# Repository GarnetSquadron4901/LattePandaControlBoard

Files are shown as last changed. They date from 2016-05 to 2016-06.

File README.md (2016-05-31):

# LattePanda FRC Driver Station
This is Garnet Squadron's next iteration to the control board. This one dumps the typical laptop and opts for a LattePanda Windows 10 single-board computer with Arduino Leonardo Co-Processor. This repo will hold Windows software, Arduino firmware, design files, and documentation.

## Features
- 16 20mA LED Outputs
- 16 General Purpose I/O
- 16 Analog Inputs
- 16 PWM Outputs
- Backup battery for safe shutdowns
- Auto power-on with AC connect
- LattePanda 
	- Windows 10 Professional
	- 4GB RAM
	- 64GB SSD
	- Intel Cherry Trail Z8300 Quad Core 1.8GHz
	- 3 USB Ports (2 USB 2.0, 1 USB 3.0)
	- Ethernet 10/100
	- 7" Capacitive Touch Screen (1024 x 600)
	- WiFi
	- Bluetooth

## How it works
The Arduino Leondaro connects with I/O expansion chips:

- Microchip MCP23017 - 16-Bit GPIO Expander with I2C Interface
- NXP PCA9685 - 16 channel PWM Driver
- TI CD74HC4067 Analog Multiplexer
- TI TLC59282 16-Channel Constant-Current LED Driver

There is a 2000 mAh LiPo battery that can provide backup power for an estimated 1 hour. While the battery life isn't great, the intended purpose is to provide power long enough to shutdown Windows 10 between matches. Override inputs will be available to:

- Keep the board powered on until battery life reaches ~5%
- Power button to turn on the system even when off of AC power.

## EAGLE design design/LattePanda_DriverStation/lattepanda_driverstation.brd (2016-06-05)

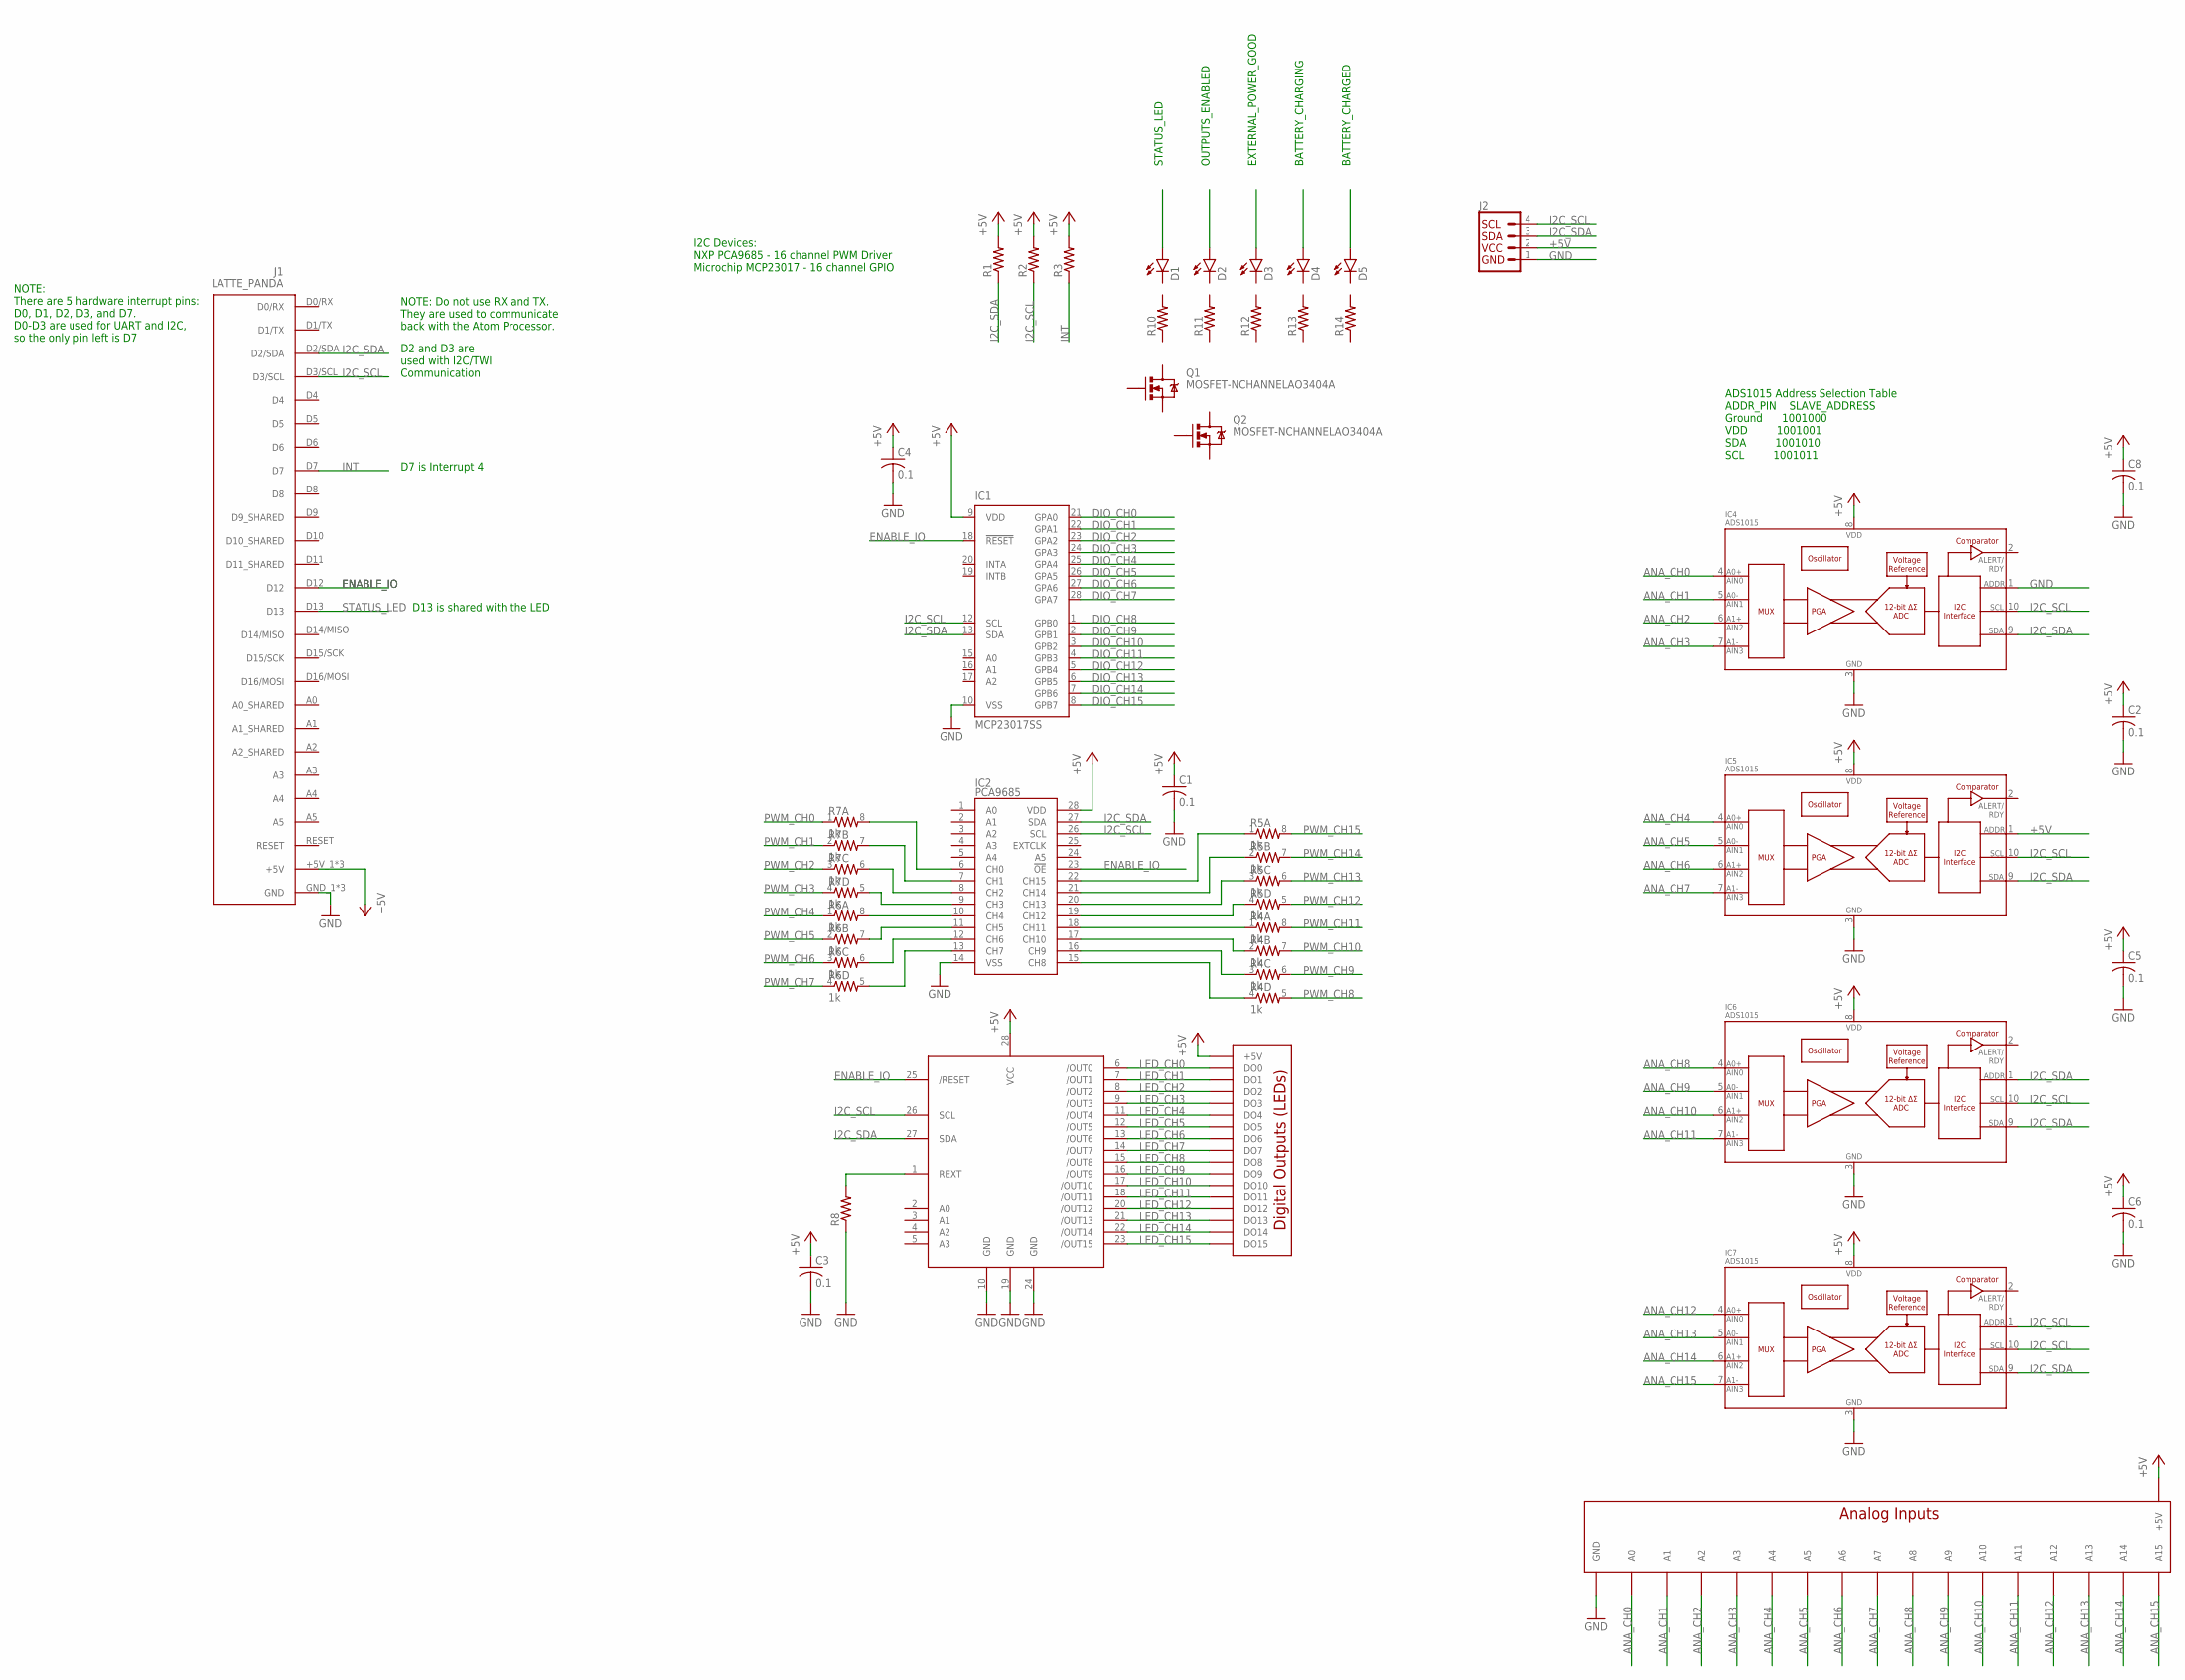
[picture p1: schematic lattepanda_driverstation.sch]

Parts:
C1, C2, C3, C4, C5, C6, C8: 0.1; C1206
D1, D2, D3, D4, D5: LED1206; LED-1206
IC1: MCP23017SS; SSOP28
IC2: PCA9685; TSSOP-28_4MM
IC3: TLC59116; TSSOP28
IC4, IC5, IC6, IC7: ADS1015; MSOP10
J1: LATTE_PANDA
J2: I2C_STANDARD; 1X04
Q1, Q2: MOSFET-NCHANNELAO3404A; SOT23-3
R1, R2, R3, R10, R11, R12, R13, R14: R-US_M1206; M1206
R4, R5, R6, R7: 1k; 0603-ARV
R8: R-US_R1206; R1206
U$1: ANALOGHEADER
U$2: DIGITALOUTPUTS; DIGITALOUT

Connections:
+5V: C1.1, C2.1, C3.1, C4.1, C5.1, C6.1, C8.1, IC1.9 (VDD), IC2.28 (VDD), IC3.28 (VCC), IC4.8 (VDD), IC5.1 (ADDR), IC5.8 (VDD), IC6.8 (VDD), IC7.8 (VDD), J1.+5V_1 (+5V), J1.+5V_2 (+5V), J1.+5V_3 (+5V), J2.2, R1.2, R2.2, R3.2, U$1.+5V@0 (+5V), U$1.+5V@1 (+5V), U$1.+5V@2 (+5V), U$1.+5V@3 (+5V), U$1.+5V@4 (+5V), U$1.+5V@5 (+5V), U$1.+5V@6 (+5V), U$1.+5V@7 (+5V), U$1.+5V@8 (+5V), U$1.+5V@9 (+5V), U$1.+5V@10 (+5V), U$1.+5V@11 (+5V), U$1.+5V@12 (+5V), U$1.+5V@13 (+5V), U$1.+5V@14 (+5V), U$1.+5V@15 (+5V), U$2.+5V@0 (+5V), U$2.+5V@1 (+5V), U$2.+5V@2 (+5V), U$2.+5V@3 (+5V), U$2.+5V@4 (+5V), U$2.+5V@5 (+5V), U$2.+5V@6 (+5V), U$2.+5V@7 (+5V), U$2.+5V@8 (+5V), U$2.+5V@9 (+5V), U$2.+5V@10 (+5V), U$2.+5V@11 (+5V), U$2.+5V@12 (+5V), U$2.+5V@13 (+5V), U$2.+5V@14 (+5V), U$2.+5V@15 (+5V)
ANA_CH0: IC4.4 (AIN0), U$1.0 (A0)
ANA_CH1: IC4.5 (AIN1), U$1.1 (A1)
ANA_CH2: IC4.6 (AIN2), U$1.2 (A2)
ANA_CH3: IC4.7 (AIN3), U$1.3 (A3)
ANA_CH4: IC5.4 (AIN0), U$1.4 (A4)
ANA_CH5: IC5.5 (AIN1), U$1.5 (A5)
ANA_CH6: IC5.6 (AIN2), U$1.6 (A6)
ANA_CH7: IC5.7 (AIN3), U$1.7 (A7)
ANA_CH8: IC6.4 (AIN0), U$1.8 (A8)
ANA_CH9: IC6.5 (AIN1), U$1.9 (A9)
ANA_CH10: IC6.6 (AIN2), U$1.10 (A10)
ANA_CH11: IC6.7 (AIN3), U$1.11 (A11)
ANA_CH12: IC7.4 (AIN0), U$1.12 (A12)
ANA_CH13: IC7.5 (AIN1), U$1.13 (A13)
ANA_CH14: IC7.6 (AIN2), U$1.14 (A14)
ANA_CH15: IC7.7 (AIN3), U$1.15 (A15)
DIO_CH0: IC1.21 (GPA0)
DIO_CH1: IC1.22 (GPA1)
DIO_CH2: IC1.23 (GPA2)
DIO_CH3: IC1.24 (GPA3)
DIO_CH4: IC1.25 (GPA4)
DIO_CH5: IC1.26 (GPA5)
DIO_CH6: IC1.27 (GPA6)
DIO_CH7: IC1.28 (GPA7)
DIO_CH8: IC1.1 (GPB0)
DIO_CH9: IC1.2 (GPB1)
DIO_CH10: IC1.3 (GPB2)
DIO_CH11: IC1.4 (GPB3)
DIO_CH12: IC1.5 (GPB4)
DIO_CH13: IC1.6 (GPB5)
DIO_CH14: IC1.7 (GPB6)
DIO_CH15: IC1.8 (GPB7)
ENABLE_IO: IC1.18 (!RESET), IC2.23 (!OE), IC3.25 (/RESET), J1.D12
GND: C1.2, C2.2, C3.2, C4.2, C5.2, C6.2, C8.2, IC1.10 (VSS), IC2.14 (VSS), IC3.10 (GND), IC3.19 (GND), IC3.24 (GND), IC4.1 (ADDR), IC4.3 (VSS), IC5.3 (VSS), IC6.3 (VSS), IC7.3 (VSS), J1.GND_1 (GND), J1.GND_2 (GND), J1.GND_3 (GND), J2.1, R8.1, U$1.GND@0 (GND), U$1.GND@1 (GND), U$1.GND@2 (GND), U$1.GND@3 (GND), U$1.GND@4 (GND), U$1.GND@5 (GND), U$1.GND@6 (GND), U$1.GND@7 (GND), U$1.GND@8 (GND), U$1.GND@9 (GND), U$1.GND@10 (GND), U$1.GND@11 (GND), U$1.GND@12 (GND), U$1.GND@13 (GND), U$1.GND@14 (GND), U$1.GND@15 (GND)
I2C_SCL: IC1.12 (SCL), IC2.26 (SCL), IC3.26 (SCL), IC4.10 (SCL), IC5.10 (SCL), IC6.10 (SCL), IC7.1 (ADDR), IC7.10 (SCL), J1.D3/SCL, J2.4, R2.1
I2C_SDA: IC1.13 (SDA), IC2.27 (SDA), IC3.27 (SDA), IC4.9 (SDA), IC5.9 (SDA), IC6.1 (ADDR), IC6.9 (SDA), IC7.9 (SDA), J1.D2/SDA, J2.3, R1.1
INT: J1.D7, R3.1
LED_CH0: IC3.6 (/OUT0), U$2.DO0
LED_CH1: IC3.7 (/OUT1), U$2.DO1
LED_CH2: IC3.8 (/OUT2), U$2.DO2
LED_CH3: IC3.9 (/OUT3), U$2.DO3
LED_CH4: IC3.11 (/OUT4), U$2.DO4
LED_CH5: IC3.12 (/OUT5), U$2.DO5
LED_CH6: IC3.13 (/OUT6), U$2.DO6
LED_CH7: IC3.14 (/OUT7), U$2.DO7
LED_CH8: IC3.15 (/OUT8), U$2.DO8
LED_CH9: IC3.16 (/OUT9), U$2.DO9
LED_CH10: IC3.17 (/OUT10), U$2.DO10
LED_CH11: IC3.18 (/OUT11), U$2.DO11
LED_CH12: IC3.20 (/OUT12), U$2.DO12
LED_CH13: IC3.21 (/OUT13), U$2.DO13
LED_CH14: IC3.22 (/OUT14), U$2.DO14
LED_CH15: IC3.23 (/OUT15), U$2.DO15
unnamed: IC2.6 (CH0), R7.8 (2)
unnamed: IC2.7 (CH1), R7.7 (2)
unnamed: IC2.8 (CH2), R7.6 (2)
unnamed: IC2.9 (CH3), R7.5 (2)
unnamed: IC2.10 (CH4), R6.8 (2)
unnamed: IC2.11 (CH5), R6.7 (2)
unnamed: IC2.12 (CH6), R6.6 (2)
unnamed: IC2.13 (CH7), R6.5 (2)
unnamed: IC2.15 (CH8), R4.4 (1)
unnamed: IC2.16 (CH9), R4.3 (1)
unnamed: IC2.17 (CH10), R4.2 (1)
unnamed: IC2.18 (CH11), R4.1
unnamed: IC2.19 (CH12), R5.4 (1)
unnamed: IC2.20 (CH13), R5.3 (1)
unnamed: IC2.21 (CH14), R5.2 (1)
unnamed: IC2.22 (CH15), R5.1
unnamed: IC3.1 (REXT), R8.2
PWM_CH0: R7.1
PWM_CH1: R7.2 (1)
PWM_CH2: R7.3 (1)
PWM_CH3: R7.4 (1)
PWM_CH4: R6.1
PWM_CH5: R6.2 (1)
PWM_CH6: R6.3 (1)
PWM_CH7: R6.4 (1)
PWM_CH8: R4.5 (2)
PWM_CH9: R4.6 (2)
PWM_CH10: R4.7 (2)
PWM_CH11: R4.8 (2)
PWM_CH12: R5.5 (2)
PWM_CH13: R5.6 (2)
PWM_CH14: R5.7 (2)
PWM_CH15: R5.8 (2)
STATUS_LED: J1.D13

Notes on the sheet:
NOTE: Do not use RX and TX. They are used to communicate back with the Atom Processor.
D13 is shared with the LED
D2 and D3 are used with I2C/TWI Communication
D7 is Interrupt 4
NOTE: There are 5 hardware interrupt pins: D0, D1, D2, D3, and D7. D0-D3 are used for UART and I2C, so the only pin left is D7
I2C Devices: NXP PCA9685 - 16 channel PWM Driver Microchip MCP23017 - 16 channel GPIO
STATUS_LED
OUTPUTS_ENABLED
EXTERNAL_POWER_GOOD
BATTERY_CHARGING
BATTERY_CHARGED
ADS1015 Address Selection Table ADDR_PIN SLAVE_ADDRESS Ground 1001000 VDD 1001001 SDA 1001010 SCL 1001011

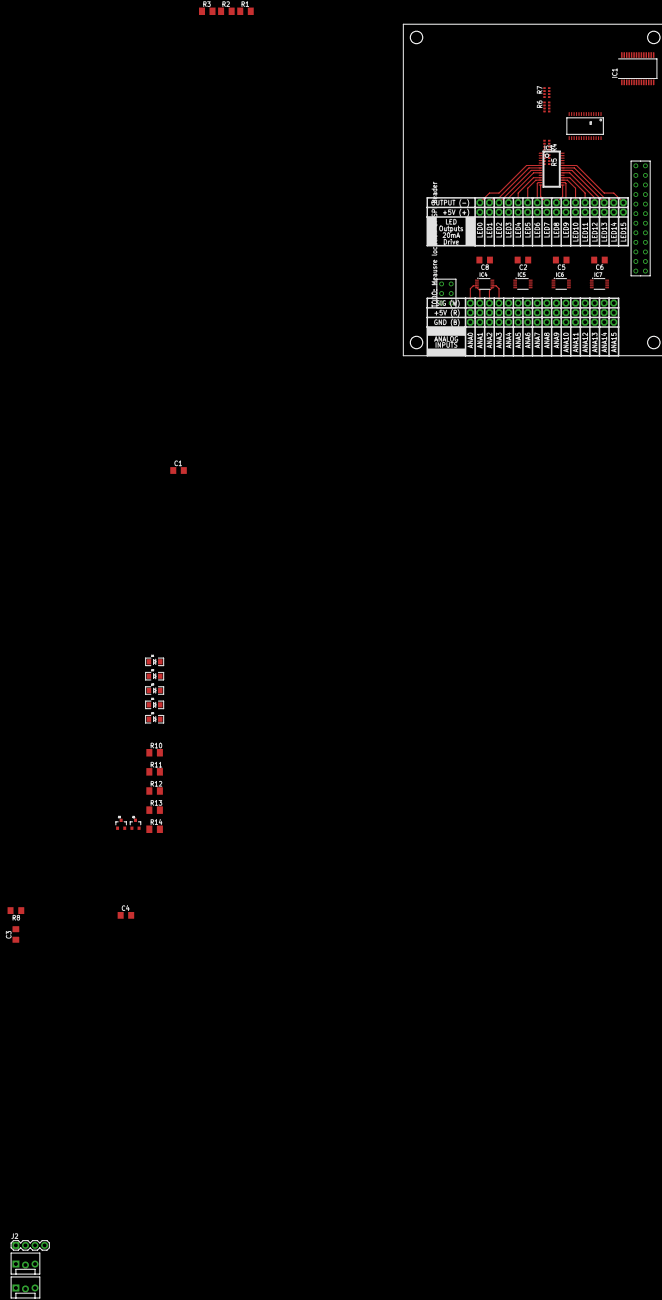
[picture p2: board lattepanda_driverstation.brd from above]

Board: 2 copper layers, 40 parts (0 on the bottom side), 55 nets.

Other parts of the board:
J3: TEMP_SENSE; MOLEX-1X3_LOCK
J4: FAN_OUT; MOLEX-1X3_LOCK

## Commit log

2016-06-01 Added start of board design.
    [lattepanda_driverstation.sch]
2016-06-03 Progress made on the schematic.
    [lattepanda_driverstation.brd, lattepanda_driverstation.sch]
2016-06-05 Progress commit.
    [lattepanda_driverstation.brd, lattepanda_driverstation.sch]

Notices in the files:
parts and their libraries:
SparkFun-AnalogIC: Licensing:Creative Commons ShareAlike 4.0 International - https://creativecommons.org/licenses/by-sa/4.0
